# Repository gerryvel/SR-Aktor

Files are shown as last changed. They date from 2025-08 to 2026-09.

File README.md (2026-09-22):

# SR Actor






## Description
This repository shows how to switch 3 relais (je 4A max with 2x2A contacts) from Chartplotter with CZone Support and also with the website support.
- Switching Relais Aktor

and send it as NNMEA2000 meassage.
- PGN 127501 // Binary Status Report
- PGN 127502 // Binary Switch Control 
- PGN 126208 // Switch Control for B&G
- PGN 130817 
- PGN 65283
- PGN 65284
- PGN 65288
- PGN 65290 CZone  

In addition, the operation of the relays, data and settings can be accessed via the website.

## Based on the work of

The project requires the NMEA2000 and the NMEA2000_esp32 libraries from Timo Lappalainen: https://github.com/ttlappalainen. 

This project is part of [OpenBoatProject](https://open-boat-projects.org/)

## Wiring diagram

grafik

## PCB Layout
PCB by Aisler: [Link](https://aisler.net/p/OFGLZJKF)

grafik
grafik

## Website

grafik





## Chartplotter

I use an B&G Vulcan 7 with Czone Support, after import the file:

Configure Czone file with the CZone Configuration tool V 6.29.22

## Fotos





## Changes

- Version 1.3.2 CZone funtion with B&G Vulcan okay
- Version 1.0 Function with Website control, Monitor on NMEA200 okay (PGN127501)

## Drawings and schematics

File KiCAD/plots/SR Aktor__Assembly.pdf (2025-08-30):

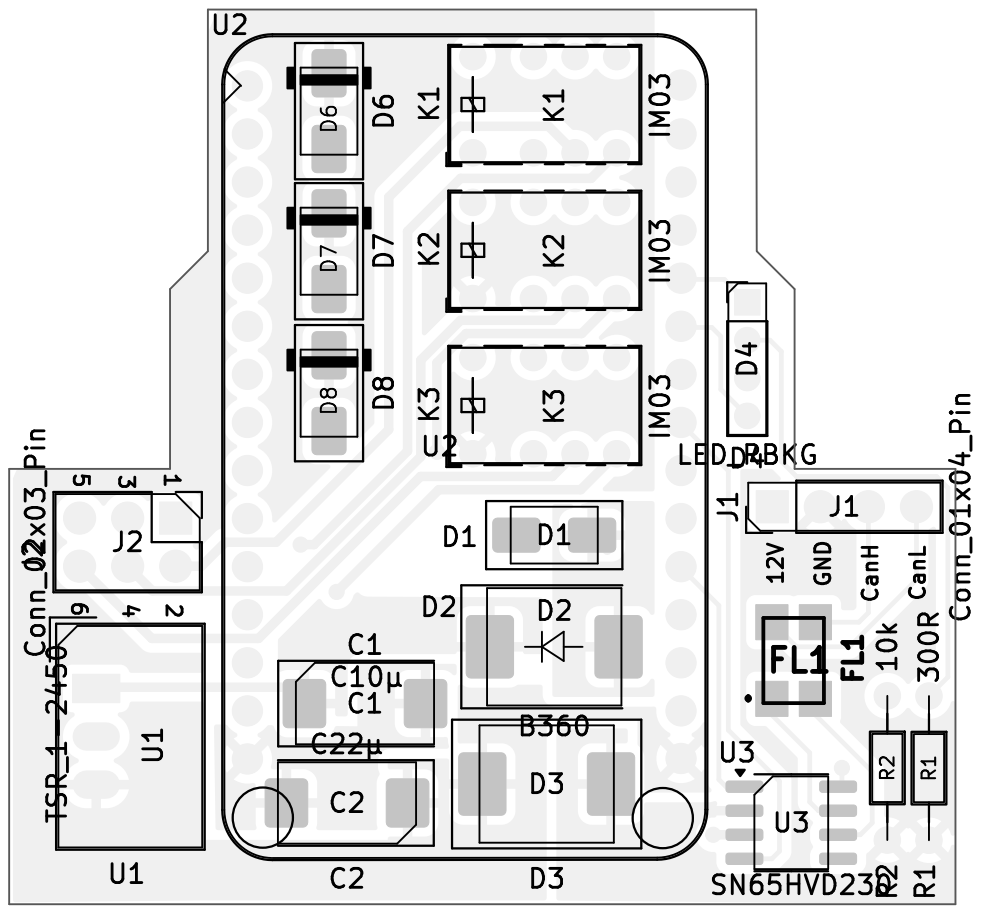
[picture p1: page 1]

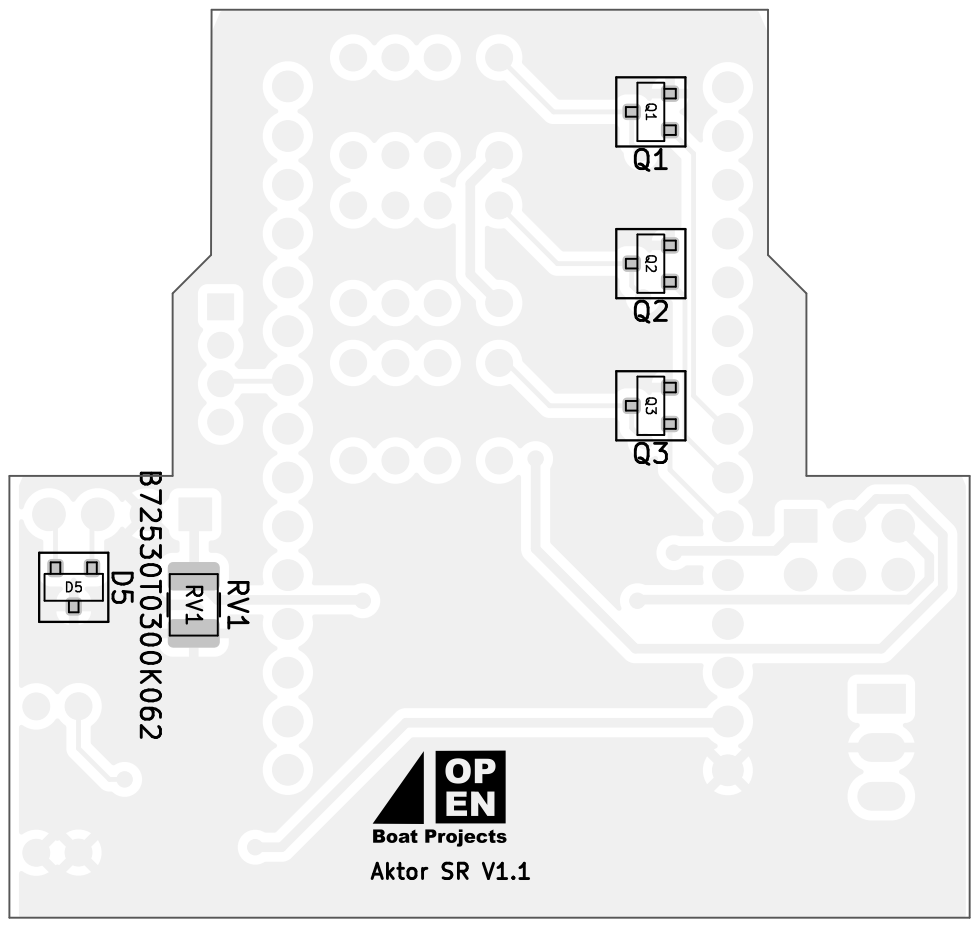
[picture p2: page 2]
Aktor SR V1.1 D5; D Date: 2025-08-23 KiCad; E.D.A. 9.0.3 Size: A4; Rev: 1.1; Id: /1 Title: SR Aktor File: SR Aktor.kicad_pcb Sheet: Black; And; White; BOT Board2Pdf:; Black; BOT -; Page 2/2

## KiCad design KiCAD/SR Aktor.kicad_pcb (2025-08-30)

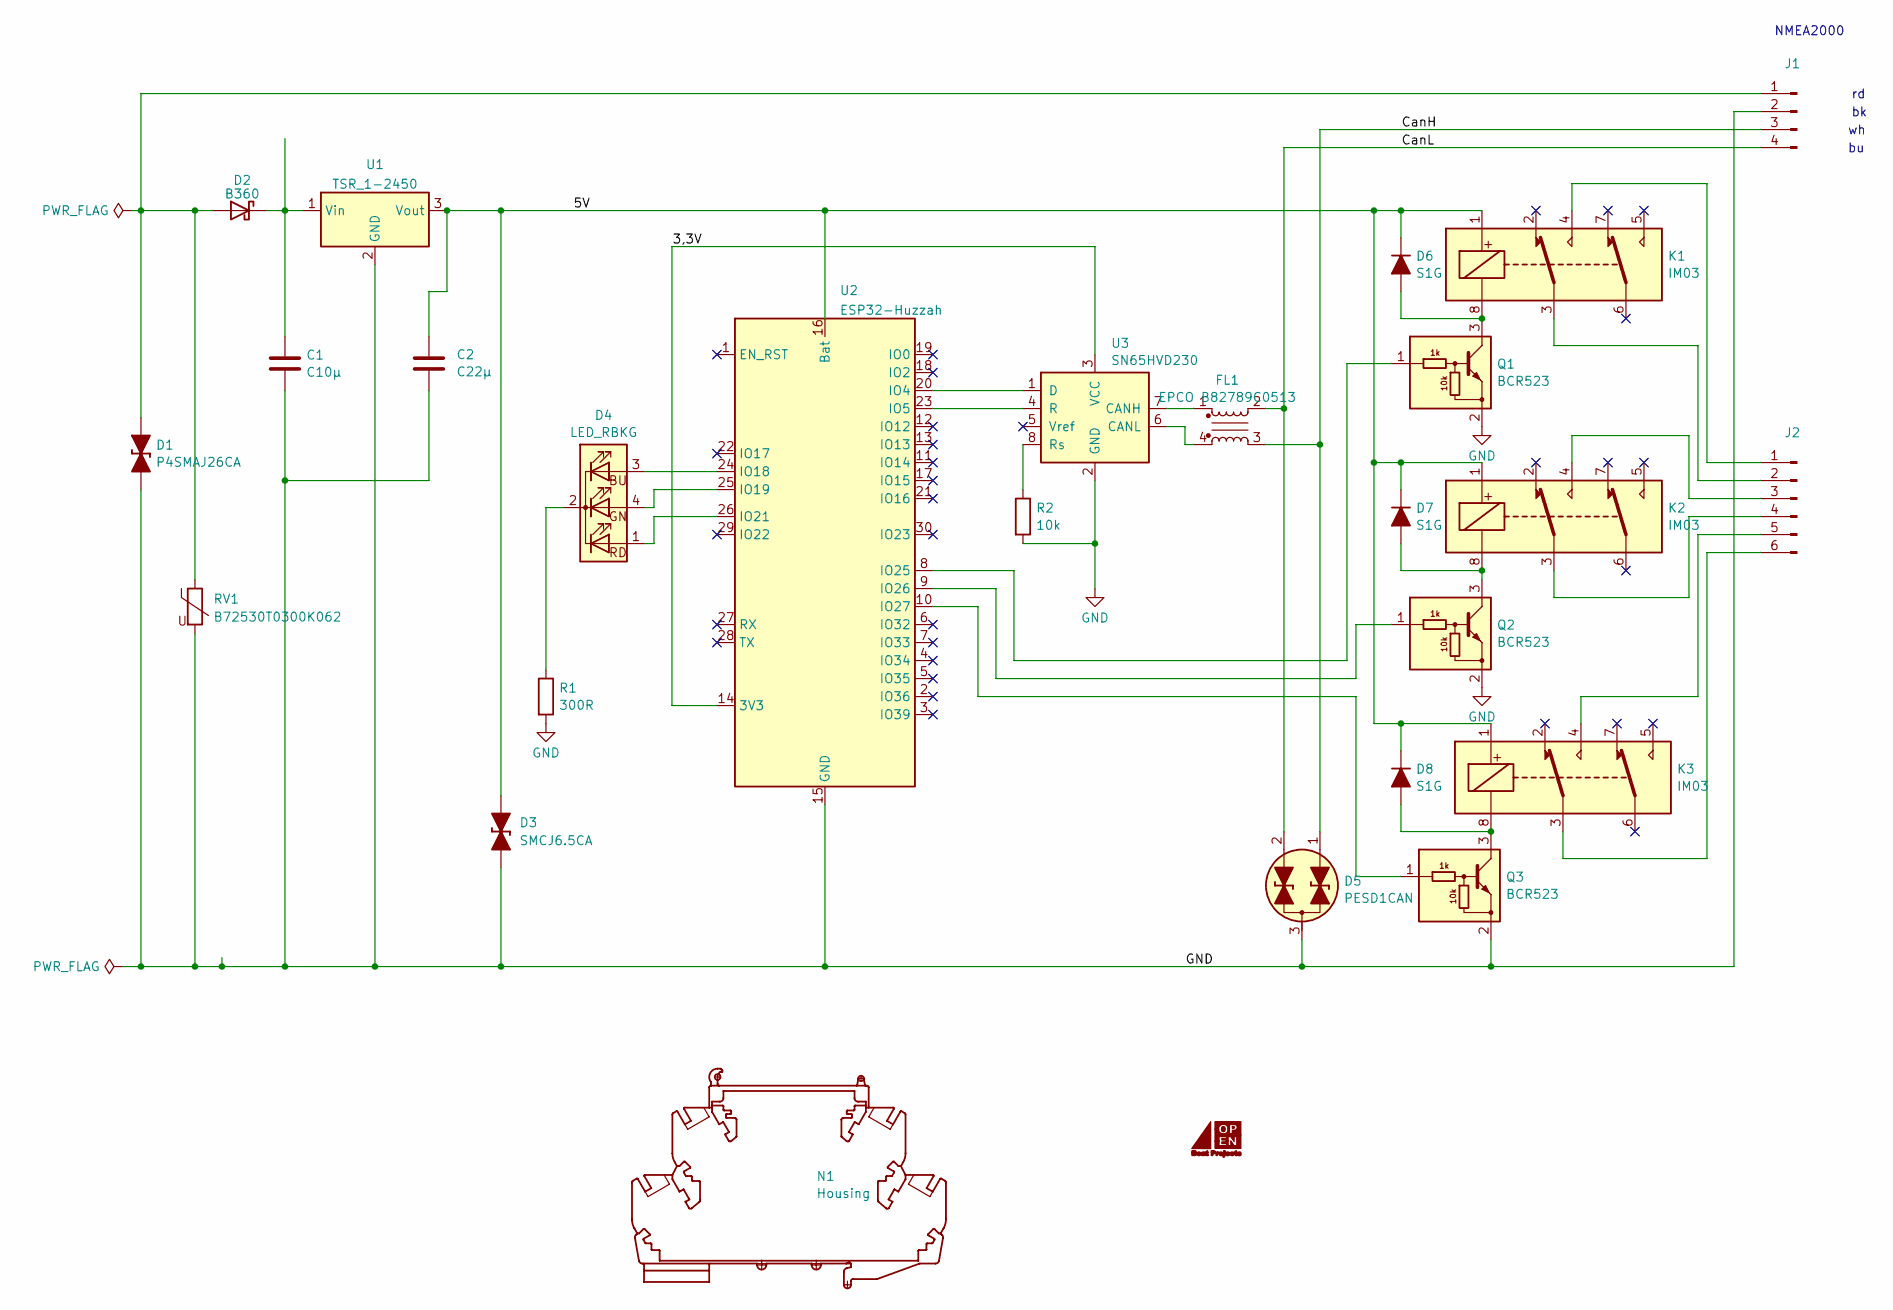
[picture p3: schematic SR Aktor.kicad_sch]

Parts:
C1: C10µ; CP_EIA-7343-15_Kemet-W_Pad2.25x2.55mm_HandSolder
C2: C22µ; CP_EIA-7343-15_Kemet-W_Pad2.25x2.55mm_HandSolder
D1: P4SMAJ26CA; D_SMA_TVS
D2: B360; D_SMC
D3: SMCJ6.5CA; D_SMC_TVS
D4: LED_RBKG; PinHeader_1x04_P2.00mm_LED RGB
D5: PESD1CAN; SOT-23
D6, D7, D8: S1G; D_SMA
FL1: EPCO B82789C0513; B82789C0113N002
G1: OpenBoat Logo; Openboatslogo
J1: Conn_01x04_Pin; PinHeader_1x04_P2.54mm_Vertical
J2: Conn_02x03_Pin; PinHeader_2x03_P2.54mm_Vertical
K1, K2, K3: IM03; Relay_DPDT_AXICOM_IMSeries_Pitch5.08mm
N1: Housing; Wago 789-120
Q1, Q2, Q3: BCR523; SOT-23
R1: 300R; R_Axial_DIN0204_L3.6mm_D1.6mm_P7.62mm_Horizontal
R2: 10k; R_Axial_DIN0204_L3.6mm_D1.6mm_P7.62mm_Horizontal
RV1: B72530T0300K062; Fuse_1210_3225Metric_Pad1.42x2.65mm_HandSolder
U1: TSR_1-2450; Converter_DCDC_TRACO_TSR-1_THT
U2: ESP32-Huzzah; Adafruit_ESP32
U3: SN65HVD230; SOIC-8_3.9x4.9mm_P1.27mm

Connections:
/3,3V: U2.14 (3V3), U3.3 (VCC)
/5V: C2.1, D3.1 (K), D6.1 (K), D7.1 (K), D8.1 (K), K1.1, K2.1, K3.1, U1.3 (Vout), U2.16 (Bat)
/CanH: D5.1 (A1), FL1.3, J1.3
/CanL: D5.2 (A2), FL1.2, J1.4
GND: C1.2, C2.2, D1.1 (K), D3.2 (A), D5.3 (Com), J1.2, Q1.2 (E), Q2.2 (E), Q3.2 (E), R1.2, R2.2, RV1.2, U1.2 (GND), U2.15 (GND), U3.2 (GND)
unnamed: D1.2 (A), D2.2 (A), J1.1, RV1.1
unnamed: C1.1, D2.1 (K), U1.1 (Vin)
unnamed: D4.1 (BA), U2.26 (IO21)
unnamed: D4.4 (GA), U2.25 (IO19)
unnamed: D4.2 (K), R1.1
unnamed: D4.3 (R), U2.24 (IO18)
unnamed: D6.2 (A), K1.8, Q1.3 (C)
unnamed: D7.2 (A), K2.8, Q2.3 (C)
unnamed: D8.2 (A), K3.8, Q3.3 (C)
unnamed: J2.1, K1.4
unnamed: J2.2, K1.3
unnamed: J2.3, K2.4
unnamed: J2.4, K2.3
unnamed: J2.5, K3.4
unnamed: J2.6, K3.3
unnamed: Q1.1 (B), U2.8 (IO25)
unnamed: Q2.1 (B), U2.9 (IO26)
unnamed: Q3.1 (B), U2.10 (IO27)
unnamed: U2.20 (IO4), U3.1 (D)
unnamed: U2.23 (IO5), U3.4 (R)
unnamed: FL1.1, U3.7 (CANH)
unnamed: FL1.4, U3.6 (CANL)
unnamed: R2.1, U3.8 (Rs)

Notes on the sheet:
NMEA2000

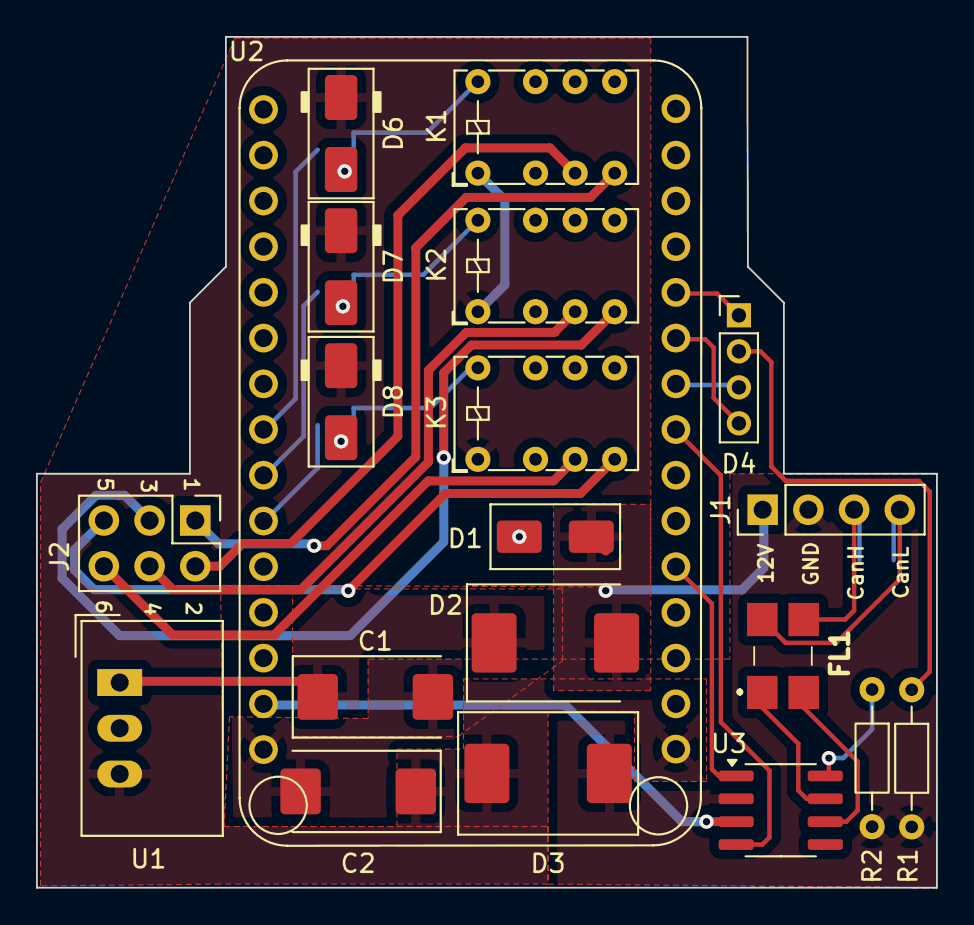
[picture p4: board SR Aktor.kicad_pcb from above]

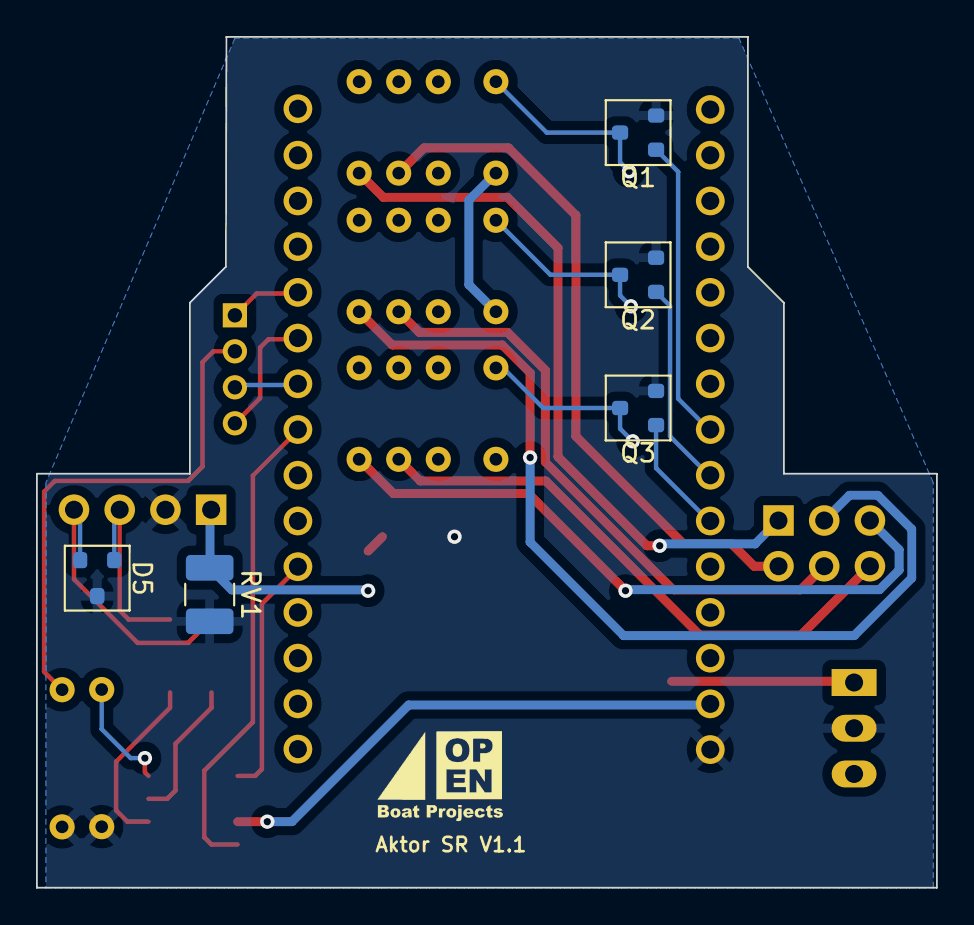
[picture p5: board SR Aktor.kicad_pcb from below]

Board: 2 copper layers, 50.0 x 47.3 mm, 26 parts (6 on the bottom side), 28 nets.

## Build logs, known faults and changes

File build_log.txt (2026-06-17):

Processing featheresp32 (platform: espressif32 @ 6.9.0; board: featheresp32; framework: arduino)
--------------------------------------------------------------------------------
Verbose mode can be enabled via `-v, --verbose` option
CONFIGURATION: https://docs.platformio.org/page/boards/espressif32/featheresp32.html
PLATFORM: Espressif 32 (6.9.0) > Adafruit ESP32 Feather
HARDWARE: ESP32 240MHz, 320KB RAM, 4MB Flash
DEBUG: Current (cmsis-dap) External (cmsis-dap, esp-bridge, esp-prog, iot-bus-jtag, jlink, minimodule, olimex-arm-usb-ocd, olimex-arm-usb-ocd-h, olimex-arm-usb-tiny-h, olimex-jtag-tiny, tumpa)
PACKAGES: 
 - framework-arduinoespressif32 @ 3.20017.241212+sha.dcc1105b 
 - tool-esptoolpy @ 1.40501.0 (4.5.1) 
 - toolchain-xtensa-esp32 @ 8.4.0+2021r2-patch5
Converting sr-aktor.ino
LDF: Library Dependency Finder -> https://bit.ly/configure-pio-ldf
LDF Modes: Finder ~ chain, Compatibility ~ soft
Found 40 compatible libraries
Scanning dependencies...
Dependency Graph
|-- ArduinoJson @ 7.4.3
|-- NMEA2000_esp32 @ 1.0.3
|-- NMEA0183 @ 1.10.1
|-- ESPAsyncWebServer-esphome @ 3.4.0
|-- NMEA2000-library @ 4.24.1
|-- WebSockets @ 2.7.3
|-- LittleFS @ 2.0.0
|-- ArduinoOTA @ 2.0.0
|-- ESPmDNS @ 2.0.0
|-- Preferences @ 2.0.0
|-- FS @ 2.0.0
|-- WiFi @ 2.0.0
|-- Wire @ 2.0.0
Building in release mode
Replace MKSPIFFSTOOL with mklittlefs.exe
Compiling .pio\build\featheresp32\src\sr-aktor.ino.cpp.o
platformio.exe : In file included from C:/Users/gerryadmin/Documents/SR 
Aktor/src/sr-aktor.ino:39:
In Zeile:1 Zeichen:1
+ & "C:\Users\gerryadmin\.platformio\penv\Scripts\platformio.exe" run - ...
+ ~~~~~~~~~~~~~~~~~~~~~~~~~~~~~~~~~~~~~~~~~~~~~~~~~~~~~~~~~~~~~~~~~~~~~
    + CategoryInfo          : NotSpecified: (In file include...r-aktor.ino:39: 
   :String) [], RemoteException
    + FullyQualifiedErrorId : NativeCommandError
 
src/web.h: In lambda function:
src/web.h:160:17: warning: 'template<unsigned int N> class 
ArduinoJson::V743PB22::StaticJsonDocument' is deprecated: use JsonDocument 
instead [-Wdeprecated-declarations]
                 StaticJsonDocument<1024> doc;
                 ^~~~~~~~~~~~~~~~~~
In file included from 
.pio/libdeps/featheresp32/ArduinoJson/src/ArduinoJson.hpp:65,
                 from 
.pio/libdeps/featheresp32/ArduinoJson/src/ArduinoJson.h:9,
                 from src/helper.h:24,
                 from C:/Users/gerryadmin/Documents/SR 
Aktor/src/sr-aktor.ino:38:
.pio/libdeps/featheresp32/ArduinoJson/src/ArduinoJson/compatibility.hpp:63:58: 
note: declared here
 class ARDUINOJSON_DEPRECATED("use JsonDocument instead") StaticJsonDocument
                                                          ^~~~~~~~~~~~~~~~~~
Linking .pio\build\featheresp32\firmware.elf
c:/users/gerryadmin/.platformio/packages/toolchain-xtensa-esp32/bin/../lib/gcc/
xtensa-esp32-elf/8.4.0/../../../../xtensa-esp32-elf/bin/ld.exe: .pio\build\feat
heresp32\src\czone.cpp.o:(.literal._ZL36SetCZoneSwitchChangeRequest127502_CZhhb
$constprop$4+0x4): undefined reference to `SetN2kSwitchBankCommand(tN2kMsg&, 
unsigned char, unsigned long long)'
c:/users/gerryadmin/.platformio/packages/toolchain-xtensa-esp32/bin/../lib/gcc/
xtensa-esp32-elf/8.4.0/../../../../xtensa-esp32-elf/bin/ld.exe: .pio\build\feat
heresp32\src\czone.cpp.o:(.literal._ZL23SetChangeSwitchState_CZhb+0x8): 
undefined reference to `BootBlockUntil'
c:/users/gerryadmin/.platformio/packages/toolchain-xtensa-esp32/bin/../lib/gcc/
xtensa-esp32-elf/8.4.0/../../../../xtensa-esp32-elf/bin/ld.exe: 
.pio\build\featheresp32\src\czone.cpp.o: in function 
`_ZL36SetCZoneSwitchChangeRequest127502_CZhhb$constprop$4':
C:\Users\gerryadmin\Documents\SR Aktor/src/czone.cpp:208: undefined reference 
to `SetN2kSwitchBankCommand(tN2kMsg&, unsigned char, unsigned long long)'
collect2.exe: error: ld returned 1 exit status
*** [.pio\build\featheresp32\firmware.elf] Error 1
========================= [FAILED] Took 25.73 seconds =========================

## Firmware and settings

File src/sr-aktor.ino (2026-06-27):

/*
  This code is free software; you can redistribute it and/or
  modify it under the terms of the GNU Lesser General Public
  License as published by the Free Software Foundation; either
  version 2.1 of the License, or (at your option) any later version.
  This code is distributed in the hope that it will be useful,
  but WITHOUT ANY WARRANTY; without even the implied warranty of
  MERCHANTABILITY or FITNESS FOR A PARTICULAR PURPOSE.  See the GNU
  Lesser General Public License for more details.
  You should have received a copy of the GNU Lesser General Public
  License along with this library; if not, write to the Free Software
  Foundation, Inc., 51 Franklin St, Fifth Floor, Boston, MA  02110-1301  USA
*/

/**
 * @file sr-aktor.ino
 * @author Gerry Sebb
 * @brief Binary Switch NMEA2000
 * @version 1.0
 * @date 2025-06-05
 * 
 * @copyright Copyright (c) 2025
 * 
 */

#include <Arduino.h>
#include "configuration.h"
#include <Preferences.h>
#include <ArduinoOTA.h>
#include <ESP_WiFi.h>
#include <ESPAsyncWebServer.h>
#include <NMEA2000_CAN.h>  // This will automatically choose right CAN library and create suitable NMEA2000 object
#include <N2kMessages.h>
#include <ESPmDNS.h>
#include <arpa/inet.h>
#include "BoardInfo.h"
#include "czone.h"
#include "helper.h"
#include "web.h"
#include "LEDindicator.h"
#include "init.h"


/******************************************* Setup *******************************************************/

// Circular buffer for raw N2k messages (store small history)
N2kRawEntry N2kRawBuf[N2KRAW_MAX];
uint8_t N2kRawHead = 0;
// Proprietary mapping storage (in RAM, persisted via writeConfig when changed)
ProprietaryMapping PropMappings[MAX_PROP_MAPPINGS];
uint8_t PropMappingCount = 0;

DetectedEvent DetectedEvents[MAX_DETECTED_EVENTS];
uint8_t DetectedEventCount = 0;

// Push an incoming raw N2k message into the circular buffer for web debug
void PushRawN2k(const tN2kMsg &msg) {
  N2kRawHead = (N2kRawHead + 1) % N2KRAW_MAX;
  N2kRawEntry &e = N2kRawBuf[N2kRawHead];
  e.pgn = msg.PGN;
  e.src = msg.Source;
  e.dst = msg.Destination;
  e.len = msg.DataLen;
  for (uint8_t i = 0; i < 8; i++) e.data[i] = (i < e.len) ? msg.Data[i] : 0xFF;
}

// Handler for incoming NMEA2000 messages. Registered in setup().
void HandleNMEA2000Msg(const tN2kMsg &N2kMsg) {
  if (N2kDebug) {
    Serial.print("Received PGN: "); Serial.println(N2kMsg.PGN);
    N2kMsg.Print(&Serial);
  }
  // Push raw message into ring buffer for web debug and save last received PGN for web inspection
  PushRawN2k(N2kMsg);
  LastReceivedN2kPGN = N2kMsg.PGN;
  LastReceivedN2kText = String("PGN:") + String(N2kMsg.PGN) + String(" Src:") + String(N2kMsg.Source) + String(" Dst:") + String(N2kMsg.Destination);

  if (CZone_HandleMsg(N2kMsg)) {
    return;
  }

  // Direct Switch Bank Control (PGN 127502)
  if (N2kMsg.PGN == 127502L) {
    unsigned char TargetBankInstance = 0;
    tN2kBinaryStatus BankStatus = 0;
    if (ParseN2kPGN127502(N2kMsg, TargetBankInstance, BankStatus)) {
    // Accept both instance 0 and 1 for compatibility with different MFD mappings.
    // or accept if broadcast and AcceptBroadcastCommands is enabled
  // Some devices use Destination==255 for global broadcast - accept both 0 and 255
  bool isBroadcast = (N2kMsg.Destination == 0 || N2kMsg.Destination == 255);
  if (TargetBankInstance == 0 || TargetBankInstance == 1 || (isBroadcast && AcceptBroadcastCommands)) {
        tN2kOnOff s1 = N2kGetStatusOnBinaryStatus(BankStatus, 1);
        tN2kOnOff s2 = N2kGetStatusOnBinaryStatus(BankStatus, 2);
      tN2kOnOff s3 = N2kGetStatusOnBinaryStatus(BankStatus, N2K_THIRD_SWITCH_ITEM);

        bool on1 = (s1 == N2kOnOff_On);
        bool on2 = (s2 == N2kOnOff_On);
      bool on3 = (s3 == N2kOnOff_On);

        digitalWrite(Relais[0], on1 ? HIGH : LOW);
        digitalWrite(Relais[1], on2 ? HIGH : LOW);
        digitalWrite(Relais[2], on3 ? HIGH : LOW);
        // Update status vars and send an immediate status report
        Rel1Status = GetRelayLogicalState(0);
        Rel2Status = GetRelayLogicalState(1);
        Rel3Status = GetRelayLogicalState(2);
        SendN2kSwitchBankStatus(Rel1Status, Rel2Status, Rel3Status);
      }
    }
    return;
  }

  // Group Function (PGN 126208) - handle Command for PGN 127502 and 127501
  // (Manche MFDs/Maretron-kompatible Stacks kommandieren die Status-PGN 127501
  //  direkt statt der Control-PGN 127502 - siehe NMEA Diskussion dazu.)
  if (N2kMsg.PGN == 126208L) {
    tN2kGroupFunctionCode gf;
    unsigned long PGNForGroupFunction;
    if (tN2kGroupFunctionHandler::Parse(N2kMsg, gf, PGNForGroupFunction)) {
      if ((PGNForGroupFunction == 127502L || PGNForGroupFunction == 127501L) && gf == N2kgfc_Command) {
        uint8_t PrioritySetting = 0;
        uint8_t NumberOfParameterPairs = 0;
        if (tN2kGroupFunctionHandler::ParseCommandParams(N2kMsg, PrioritySetting, NumberOfParameterPairs)) {
          int Index = 0;
          if (tN2kGroupFunctionHandler::StartParseCommandPairParameters(N2kMsg, Index)) {
            // Allow broadcast commands when enabled - some send Dst==0, others Dst==255
            bool isBroadcast = (N2kMsg.Destination == 0 || N2kMsg.Destination == 255);
            if (N2kMsg.Destination != NodeAddress && !(isBroadcast && AcceptBroadcastCommands)) {
              // Not for us
              return;
            }
            for (uint8_t p = 0; p < NumberOfParameterPairs; p++) {
              uint8_t FieldNo = N2kMsg.GetByte(Index);
              uint8_t FieldValue = N2kMsg.GetByte(Index);
              // Field 1 = Bank Instance (skip), Felder 2..4 = Switch 1..3 Status in beiden PGNs
              if (FieldNo >= 2 && FieldNo <= 4) {
                bool on = (FieldValue != 0);
                digitalWrite(Relais[FieldNo - 2], on ? HIGH : LOW);
              } else if (FieldNo >= 1 && FieldNo <= 3) {
                // Fallback fuer Stacks, die wie urspruenglich ab Feld 1 zaehlen
                bool on = (FieldValue != 0);
                digitalWrite(Relais[FieldNo - 1], on ? HIGH : LOW);
              }
            }
            // Update status vars and send an immediate status report
            Rel1Status = digitalRead(Relais[0]);
            Rel2Status = digitalRead(Relais[1]);
            Rel3Status = digitalRead(Relais[2]);
            SendN2kSwitchBankStatus(Rel1Status, Rel2Status, Rel3Status);
            if (N2kDebug) {
              Serial.printf("GroupFunction Command auf PGN %lu verarbeitet\n", PGNForGroupFunction);
            }
          }
        }
      }
    }
    return;
  }
}

void setup() {

  initSerial();
  delay(2000);
  initLittleFS();

	/**
	 * @brief file exists, reading and loading config file
	 * 
	 */
  readConfig("/config.json");
    IP = inet_addr(tAP_Config.wAP_IP);
    AP_SSID = tAP_Config.wAP_SSID;
    AP_PASSWORD = tAP_Config.wAP_Password;
    sRelay1Name = tAP_Config.wRelay1Name;
    sRelay2Name = tAP_Config.wRelay2Name;
    sRelay3Name = tAP_Config.wRelay3Name;
    Serial.println("\nConfigdata : AP IP: " + IP.toString() + ", AP SSID: " + AP_SSID + " , Passwort: " + AP_PASSWORD + " , Relais1: " + sRelay1Name + " , Relais2: " + sRelay2Name + " , Relais3: " + sRelay3Name + " read from file");

  // IO Inits
  LEDInit();
  initRelays();

  // Boardinfo	11
  /**
   * @brief 
   * Read Boardinfo for output 
   */
    sBoardInfo = boardInfo.ShowChipIDtoString();

	//Wifi
  WiFi.mode(WIFI_AP_STA);
  WiFi.softAPdisconnect();
  if(WiFi.softAP(AP_SSID, AP_PASSWORD, channel, hide_SSID, max_connection)){
    WiFi.softAPConfig(IP, Gateway, NMask);
    Serial.println("\nAccesspoint " + String(AP_SSID) + " running");
    Serial.println("\nSet IP " + IP.toString() + ", Gateway: " + Gateway.toString() + ", NetMask: " + NMask.toString() + " ready");
    LEDon(LED(Green));
    delay(1000);
    LEDoff(LED(Green));
  } else {
      Serial.println(F("Starting AP failed."));
      LEDon(LED(Red));  
      delay(1000); 
      ESP.restart();
  }

  WiFi.setHostname(HostName);
  Serial.println("Set Hostname " + String(WiFi.getHostname()) + " done\n");

  delay(1000);
  WiFiDiag();

	if (!MDNS.begin(AP_SSID)) {
		Serial.println(F("Error setting up MDNS responder!"));
		while (1) {
			delay(1000);
		}
	}
  Serial.println("mDNS responder started\n");

// Start TCP (HTTP) server
	server.begin();
	Serial.println("TCP server started\n");

// Add service to MDNS-SD
	MDNS.addService("http", "tcp", 80);
  MDNS.addService("ws", "tcp", 81);

// Webconfig laden
  initWebsite();
  
// Init NMEA2000
  initNMEA2000();
  CZone_Init();

  // Register incoming NMEA2000 message handler so we can react to remote commands
  NMEA2000.SetMsgHandler(HandleNMEA2000Msg);

/**
 * @brief OTA
 * 
 */
  ArduinoOTA
    .onStart([]() {
      String type;
      if (ArduinoOTA.getCommand() == U_FLASH)
        type = "sketch";
      else // U_SPIFFS
        type = "filesystem";

      // NOTE: if updating SPIFFS this would be the place to unmount SPIFFS using SPIFFS.end()
      Serial.println("Start updating " + type);
    })
    .onEnd([]() {
      Serial.println("\nEnd");
    })
    .onProgress([](unsigned int progress, unsigned int total) {
      Serial.printf("Progress: %u%%\r", (progress / (total / 100)));
    })
    .onError([](ota_error_t error) {
      Serial.printf("Error[%u]: ", error);
      if (error == OTA_AUTH_ERROR) Serial.println("Auth Failed");
      else if (error == OTA_BEGIN_ERROR) Serial.println("Begin Failed");
      else if (error == OTA_CONNECT_ERROR) Serial.println("Connect Failed");
      else if (error == OTA_RECEIVE_ERROR) Serial.println("Receive Failed");
      else if (error == OTA_END_ERROR) Serial.println("End Failed");
    });

  ArduinoOTA.begin();
 
  printf("Setup end\n");
}

bool IsTimeToUpdate(unsigned long NextUpdate) {
  return (NextUpdate < millis());
}
unsigned long InitNextUpdate(unsigned long Period, unsigned long Offset = 0) {
  return millis() + Period + Offset;
}

void SetNextUpdate(unsigned long &NextUpdate, unsigned long Period) {
  while ( NextUpdate < millis() ) NextUpdate += Period;
}

/************************ n2k Datenfunktionen ***************************/

/**
 * @brief Send PGN127501
 * 
 * @param Switchbank 
 */
void SendN2kSwitchBankStatus(bool Status1, bool Status2, bool Status3) {
  static unsigned long SlowDataUpdated = InitNextUpdate(SlowDataUpdatePeriod, SwitchStatusSendOffset);
  tN2kMsg N2kMsg;
  tN2kBinaryStatus bankStatus;

  if ( IsTimeToUpdate(SlowDataUpdated) ) {
    SetNextUpdate(SlowDataUpdated, SlowDataUpdatePeriod);
    N2kResetBinaryStatus(bankStatus);

    // Read actual logical relay states at send time to avoid stale values
    Status1 = GetRelayLogicalState(0);
    Status2 = GetRelayLogicalState(1);
    Status3 = GetRelayLogicalState(2);
    Serial.printf("R1 Status     : %s \n", Status1 ? "On" : "Off");
    Serial.printf("R2 Status     : %s \n", Status2 ? "On" : "Off");
    Serial.printf("R3 Status     : %s \n", Status3 ? "On" : "Off");

    const bool report1 = InvertN2kStatus ? !Status1 : Status1;
    const bool report2 = InvertN2kStatus ? !Status2 : Status2;
    const bool report3 = InvertN2kStatus ? !Status3 : Status3;

    // Build full bank status and place relay 3 on configured item index.
    N2kSetStatusBinaryOnStatus(bankStatus, report1 ? N2kOnOff_On : N2kOnOff_Off, 1);
    N2kSetStatusBinaryOnStatus(bankStatus, report2 ? N2kOnOff_On : N2kOnOff_Off, 2);
    N2kSetStatusBinaryOnStatus(bankStatus, report3 ? N2kOnOff_On : N2kOnOff_Off, N2K_THIRD_SWITCH_ITEM);
    // Explicitly set a 4th item (always Off) - the Vulcan device manager seems to only
    // render switch banks whose items are explicitly On/Off rather than left as the
    // default "Unavailable" state. Confirmed previously: a 4th explicit item made
    // item 4 appear as "0.4" in the device manager.
    N2kSetStatusBinaryOnStatus(bankStatus, N2kOnOff_Off, 4);
    SetN2kPGN127501(N2kMsg, 0, bankStatus);

        // Diagnostic: print message bytes only when N2kDebug is enabled.
    if (N2kDebug) {
      N2kMsg.Print(&Serial);
    }

    // Send only when we updated the message
    NMEA2000.SendMsg(N2kMsg);
  }
}


void SetN2kPGN126208(tN2kMsg &N2kMsg, unsigned char DeviceBankInstance, tN2kBinaryStatus BankStatus) {
    N2kMsg.SetPGN(126208L);
    N2kMsg.Priority=3;
	BankStatus = (BankStatus << 8) | DeviceBankInstance;
	N2kMsg.AddUInt64(BankStatus);
}  

//*****************************************************************************
inline void SetN2kSwitchBankCommand(tN2kMsg &N2kMsg, unsigned char DeviceBankInstance, tN2kBinaryStatus BankStatus) {
  SetN2kPGN127502(N2kMsg,DeviceBankInstance,BankStatus);
}

//*****************************************************************************
void SetSwitch(unsigned char DeviceBankInstance, uint8_t SwitchIndex, bool ItemStatus) {
  tN2kBinaryStatus BankStatus;
  tN2kMsg N2kMsg;

  N2kResetBinaryStatus(BankStatus);
  N2kSetStatusBinaryOnStatus(BankStatus,ItemStatus?N2kOnOff_On:N2kOnOff_Off,SwitchIndex);
  SetN2kSwitchBankCommand(N2kMsg,DeviceBankInstance,BankStatus);
  NMEA2000.SendMsg(N2kMsg);
}

#define PRIORITY_DO_NOT_CHANGE    0x08
#define RESERVED_4_BITS_SET_TO_1  0x0f

void SetN2kGroupFunctionCommand126208(tN2kMsg &N2kMsg, unsigned char DestinationId,
                     unsigned char FieldNoOfParam, unsigned char FieldValue) {
    N2kMsg.SetPGN(126208L);
    N2kMsg.Priority    = 3;
    N2kMsg.Destination = DestinationId;
    N2kMsg.AddByte(N2kgfc_Command);     // field 1
    N2kMsg.Add3ByteInt(126208L);        // field 2 : Commanded PGN
                                        // field 3 : Priority Setting
                                        // field 4 : NMEA Reserved
    N2kMsg.AddByte(PRIORITY_DO_NOT_CHANGE | RESERVED_4_BITS_SET_TO_1<<4);
    N2kMsg.AddByte(1);                  // field 5 : Number of Pairs .. to follow
    N2kMsg.AddByte(FieldNoOfParam);     // field 6 : Field No of commanded param
    N2kMsg.AddByte(FieldValue);         // field 7 : Value of commanded param
}

void sendSwitchCommand(unsigned char DestinationId, unsigned char FieldNoOfParam, unsigned char FieldValue)
{
    tN2kMsg N2kMsg;
    SetN2kGroupFunctionCommand126208(N2kMsg, DestinationId, FieldNoOfParam, FieldValue);
    NMEA2000.SendMsg(N2kMsg);
}
  
void CheckSourceAddressChange() {
  int SourceAddress = NMEA2000.GetN2kSource();

  if (SourceAddress != NodeAddress) { // Save potentially changed Source Address to NVS memory 
    NodeAddress = SourceAddress;      // Set new Node Address (to save only once)
    preferences.begin("nvs", false);
    preferences.putInt("LastNodeAddress", SourceAddress);
    preferences.end();
    Serial.printf("Address Change: New Address=%d\n", SourceAddress);
  }
}
/************************************ Loop ***********************************/
void loop() {
  static unsigned long lastSwitchControlAnnounce = 0;

  SendN2kSwitchBankStatus(Rel1Status, Rel2Status, Rel3Status);

  // Compatibility: periodically announce full switch control bank (PGN127502)
  // so MFDs can build a full switch list reliably.
  if (millis() - lastSwitchControlAnnounce >= 1000UL) {
    tN2kBinaryStatus controlBankStatus;
    tN2kMsg controlMsg;

    lastSwitchControlAnnounce = millis();

    Rel1Status = GetRelayLogicalState(0);
    Rel2Status = GetRelayLogicalState(1);
    Rel3Status = GetRelayLogicalState(2);

    N2kResetBinaryStatus(controlBankStatus);
    N2kSetStatusBinaryOnStatus(controlBankStatus, Rel1Status ? N2kOnOff_On : N2kOnOff_Off, 1);
    N2kSetStatusBinaryOnStatus(controlBankStatus, Rel2Status ? N2kOnOff_On : N2kOnOff_Off, 2);
    N2kSetStatusBinaryOnStatus(controlBankStatus, Rel3Status ? N2kOnOff_On : N2kOnOff_Off, N2K_THIRD_SWITCH_ITEM);
    N2kSetStatusBinaryOnStatus(controlBankStatus, N2kOnOff_Off, 4);

    SetN2kSwitchBankCommand(controlMsg, 0, controlBankStatus);
    NMEA2000.SendMsg(controlMsg);
  }

  NMEA2000.ParseMessages();
  CZone_Loop();
  CheckSourceAddressChange();

  // Dummy to empty input buffer to avoid board to stuck with e.g. NMEA Reader
  if ( Serial.available() ) {
    Serial.read();
  }


// OTA	
	ArduinoOTA.handle();

/**
 * @brief Actual Website Data
 * 
 */
  
    sCL_Status = sWifiStatus(WiFi.status());
    sAP_Station = WiFi.softAPgetStationNum();
    freeHeapSpace();

  Rel1Status = GetRelayLogicalState(0);
  Rel2Status = GetRelayLogicalState(1);
  Rel3Status = GetRelayLogicalState(2);
    
/**
 * @brief Construct a new if object
 * Reboot from Website
*/
  if (IsRebootRequired) {
      Serial.println("Rebooting ESP32: "); 
      delay(1000); // give time for reboot page to load
      ESP.restart();
      }

	// LED Indicator
    LoopIndicator();

}

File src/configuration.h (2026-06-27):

#ifndef __configuration__H__
#define __configuration__H__

/**
 * @file configuration.h
 * @author Gerry Sebb
 * @brief Konfiguration fÃ¼r GPIO und Variable
 * @version 2.3
 * @date 2025-01-06
 */

// Core Arduino includes (provides String, IPAddress, uint8_t, etc.)
#include <Arduino.h>
#include <Preferences.h>

// Versionierung
#define VersionSoftware "1.3.1.0 (2026-06-26)"  // Version Software
#define VersionHardware "1.1.0.0 (2025-08-07)"  // Version Hardware

/**
 * @brief Config NMEA2000
 */
#define ESP32_CAN_TX_PIN GPIO_NUM_4  // Set CAN TX port to 4 
#define ESP32_CAN_RX_PIN GPIO_NUM_5  // Set CAN RX port to 5
#define N2K_SOURCE 15

// --- Test-Schalter: CZone Protokoll komplett aktivieren/deaktivieren ---
// 1 = CZone Pakete werden gesendet/verarbeitet (Originalverhalten)
// 0 = Nur Standard-NMEA2000 PGNs (127501/127502/126208), kein CZone-Traffic.
//     Zum Testen, ob das MFD auch ohne CZone eine Switching-Seite anlegt.
#ifndef ENABLE_CZONE
#define ENABLE_CZONE 1
#endif

// General timing / offsets
#define SwitchControlSendOffset 0
#define SwitchStatusSendOffset 40
#define RPMSendOffset 80
#define BatteryDCSendOffset 120
#define BatteryDCStatusSendOffset 160
#define SlowDataUpdatePeriod 1000  // Time between CAN Messages sent
// NMEA2000 item index for the third relay on PGN127501/127502.
// Vulcan CZone 6.11.8.0 only showed all three relays reliably when relay 3
// stayed on item 3 and slot 4 was still sent as an explicit unavailable slot.
#define N2K_THIRD_SWITCH_ITEM 3

// Configuration Website
#define PAGE_REFRESH 10 // x Sec.
#define WEB_TITEL "SR03 Module"
extern String sHeapspace;

// Configuration mit Webinterface
struct Web_Config
{
	char wAP_IP[20];
	char wAP_SSID[64];
	char wAP_Password[12];
	char wRelay1Name[12];
	char wRelay2Name[12];
	char wRelay3Name[12];
	char wADC2_Cal[6];
};
extern Web_Config tAP_Config;

// Configuration AP
#define HostName "BinarySwitch"
#define CHANNEL_DEFAULT 10
#define HIDE_SSID_DEFAULT false
#define MAX_CONNECTIONS_DEFAULT 2

// Variables for WIFI-AP
extern IPAddress IP;
extern IPAddress Gateway;
extern IPAddress NMask;
extern const char* AP_SSID;
extern const char* AP_PASSWORD;
extern IPAddress AP_IP;
extern IPAddress CL_IP;
extern IPAddress SELF_IP;
extern String sAP_Station;

// Node address and persistent preferences
extern int NodeAddress;
extern Preferences preferences;

// AP runtime settings (provide variables for legacy code using 'channel', 'hide_SSID', 'max_connection')
extern int channel;
extern bool hide_SSID;
extern int max_connection;

// --- Definitions for internal helper types used by N2k debugging and mappings ---
// Keep these lightweight so they can be used from multiple compilation units.
#ifndef N2KRAW_MAX
#define N2KRAW_MAX 16
#endif

#ifndef MAX_PROP_MAPPINGS
#define MAX_PROP_MAPPINGS 32
#endif

#ifndef MAX_DETECTED_EVENTS
#define MAX_DETECTED_EVENTS 32
#endif

// Raw N2k message entry used for web debug buffer
struct N2kRawEntry {
	uint32_t pgn;
	uint8_t src;
	uint8_t dst;
	uint8_t len;
	uint8_t data[8];
};

// Simple mapping definition: pgn, byte offset, expected value, relay index (1..), action
struct ProprietaryMapping {
	uint32_t pgn;
	uint8_t offset;
	uint8_t value;
	uint8_t relay;
	uint8_t action;
};

// Detected event cached for edge-detection
struct DetectedEvent {
	uint32_t pgn;
	unsigned long lastSeen;
	uint8_t count;
	uint8_t len;
	uint8_t data[32];
};

// Configuration Client (Network Data Windsensor)
#define CL_SSID "NoWa"
#define CL_PASSWORD "12345678"
extern int iSTA_on;
extern int bConnect_CL;
extern bool bClientConnected;

// Calibration data variable definition for ADC1 and ADC2 Input
extern double ADC_Calibration_Value1;
extern double ADC_Calibration_Value2;

// Configuration Sensors I2C
#define I2C_SDA 21
#define I2C_SCL 22
#define SEALEVELPRESSURE_HPA (1013.25)
extern float fbmp_temperature;
extern float fbmp_pressure;
extern float fbmp_altitude;
extern String sI2C_Status;
extern bool bI2C_Status;

// Global Data Sonar
const int iMaxSonar = 35;
extern int iDistance;

// Global Data Motor data
extern float FuelLevel;
extern float FuelLevelMax;
extern float CoolantTemp;
extern float MotorTemp;
extern float EngineRPM;
extern float BordSpannung;
extern bool EngineOn;
extern String motorErrorReported;
extern String coolantErrorReported;
extern unsigned long Counter;
enum EngineStatus { Off = 0, On = 1 };
#define RPM_Calibration_Value 4.0
#define Eingine_RPM_Pin 19

// Global Data Battery
extern int Bat1Capacity;
extern int Bat2Capacity;
extern int SoCError;
extern float BatSoC;

// Data wire for temperature (Dallas DS18B20)
#define ONE_WIRE_BUS 14
extern String sOneWire_Status;

// Variables Website
extern float fDrehzahl;
extern float fGaugeDrehzahl;
extern float fBordSpannung;
extern float fCoolantTemp;
extern float fMotorTemp;
extern float fCoolantOffset;
extern float fMotorOffset;
extern String sSTBB;
extern String sOrient;
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

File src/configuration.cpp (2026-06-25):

#include "configuration.h"

// Node address and persistent preferences
int NodeAddress = 33;
Preferences preferences;
uint8_t chipid[6] = {0};
uint32_t id = 0;
int i = 0;

String sHeapspace = "";
Web_Config tAP_Config;

IPAddress IP = IPAddress(192, 168, 15, 25);
IPAddress Gateway = IPAddress(192, 168, 15, 25);
IPAddress NMask = IPAddress(255, 255, 255, 0);
const char* AP_SSID = "BinarySwitch";
const char* AP_PASSWORD  = "12345678";
IPAddress AP_IP;
IPAddress CL_IP;
IPAddress SELF_IP;
String sAP_Station = "";

int iSTA_on = 0;
int bConnect_CL = 0;
bool bClientConnected = false;

// AP runtime settings (legacy names)
int channel = CHANNEL_DEFAULT;
bool hide_SSID = HIDE_SSID_DEFAULT;
int max_connection = MAX_CONNECTIONS_DEFAULT;

double ADC_Calibration_Value1 = 170.0;
double ADC_Calibration_Value2 = 19.0;

float fbmp_temperature = 0;
float fbmp_pressure = 0;
float fbmp_altitude = 0;
String sI2C_Status = "";
bool bI2C_Status = false;

int iDistance = 0;

float FuelLevel = 0;
float FuelLevelMax = 30;
float CoolantTemp = 0;
float MotorTemp = 0;
float EngineRPM = 0;
float BordSpannung = 0;
bool EngineOn = false;
String motorErrorReported = "Aus";
String coolantErrorReported = "Aus";
unsigned long Counter = 0;

int Bat1Capacity = 55;
int Bat2Capacity = 90;
int SoCError = 0;
float BatSoC = 0;

String sOneWire_Status = "";

float fDrehzahl = 0;
float fGaugeDrehzahl = 0;
float fBordSpannung = 0;
float fCoolantTemp = 0;
float fMotorTemp = 0;
float fCoolantOffset = 0;
float fMotorOffset = 0;
String sSTBB = "";
String sOrient = "";

double dMWV_WindDirectionT = 0;
double dMWV_WindSpeedM = 0;
double dVWR_WindDirectionM = 0;
double dVWR_WindAngle = 0;
double dVWR_WindSpeedkn = 0;
double dVWR_WindSpeedms = 0;

const char *udpAddress = "192.168.30.255";
const int udpPort = 4444;

int Relais[NUM_RELAYS] = {25, 26, 27};
int SwitchSet = 0;
bool Rel1Status = false;
bool Rel2Status = false;
bool Rel3Status = false;
// By default, allow MFD commands to control all relays
bool RelayAllowMFD[NUM_RELAYS] = { true, true, true };
String sRelay1Name = "";
String sRelay2Name = "";
String sRelay3Name = "";
// Default: ensure relays powered-off at start to avoid accidental activation
bool ForceRelaysOffAtBoot = true;
// Default: report relay states without inversion.
bool InvertN2kStatus = false;

bool N2kDebug = false;
bool AcceptBroadcastCommands = true;
bool CZoneEnableConfigProtocol = true;
unsigned long LastReceivedN2kPGN = 0;
String LastReceivedN2kText = "";
unsigned long BootBlockUntil = 0;

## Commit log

2025-04-06 V 0.9
    [configuration.h, partitions_custom.csv]
2025-08-22 V 1.0
    [configuration.h]
2025-08-30 Kicad added
    [SR Aktor.kicad_pcb, SR Aktor.kicad_sch]
2025-10-08 V 1.0.1
    [configuration.h]
2025-10-21 Replace wiring diagram image in README
    Updated wiring diagram image in README.
2026-06-17 V 1.1
    [configuration.h]
2026-06-18 V 1.2
    [configuration.h]
2026-06-25 V 1.3
    [configuration.h]
2026-06-26 V 1.3 CZone Schalten&Status okay, Geräteansicht 3 Relais okay
    [configuration.h]
2026-06-26 V 1.3.1
    [configuration.h]
2026-06-26 V1.3.1 stable Czone/N2k N2K behavior (switching+status+device list)
    [configuration.h]
2026-06-26 V 1.3.2 cleaning
    [configuration.h]
2026-06-26 V 1.3.2
    [configuration.h]
